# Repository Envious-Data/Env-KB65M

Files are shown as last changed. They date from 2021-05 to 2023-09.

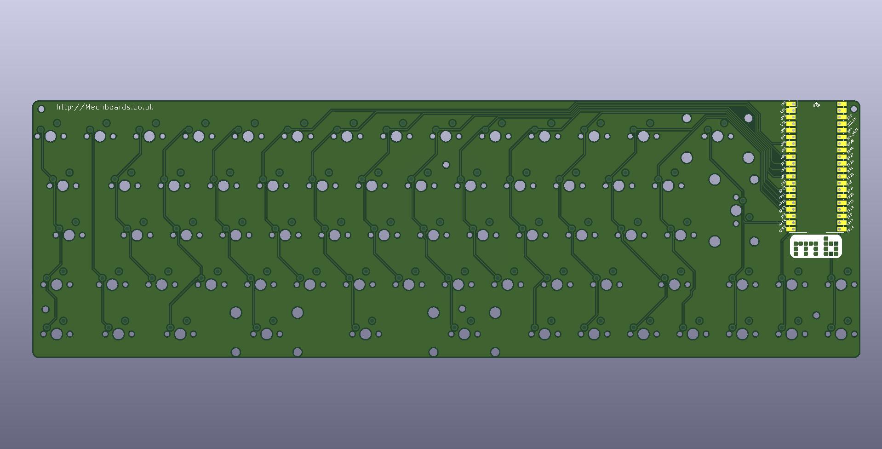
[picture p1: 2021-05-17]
EnvKB65.jpg

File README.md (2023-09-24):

# Env-KB65M
 A 65% Custom Mechanical utilising the raspberry pi pico.
  
### About
A compact 65% design featuring ISO and ANSI layout support as well as a triple split spacebar. I designed this on a whim so its design can be considered somewhat quirky.

### Firmware
If you need a pre-built QMK firmware for this keyboard you can find it [here](https://raw.githubusercontent.com/Envious-Data/EnvKB-QMK/main/_PREBUILTFIRMWARES/enviousdesign_65m_default.uf2)
and [here](https://raw.githubusercontent.com/Envious-Data/EnvKB-QMK/main/_PREBUILTFIRMWARES/enviousdesign_65m_via.uf2)

### how to flash
- hold BOOTSEL button while plugging in USB
- A USB Drive will show up, drag and drop the UF2 file linked above into the Drive
- Done!

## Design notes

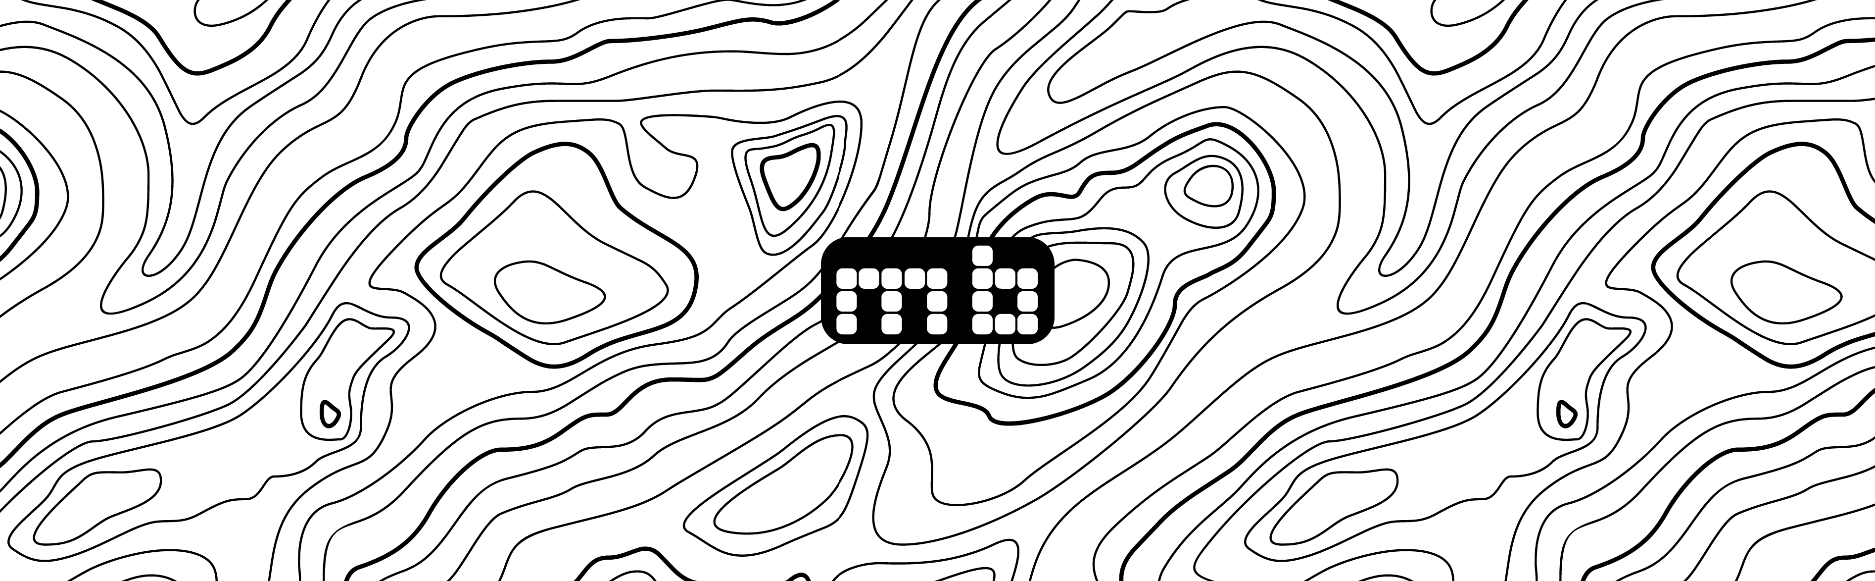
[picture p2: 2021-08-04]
BottomPCB/graphictest.png

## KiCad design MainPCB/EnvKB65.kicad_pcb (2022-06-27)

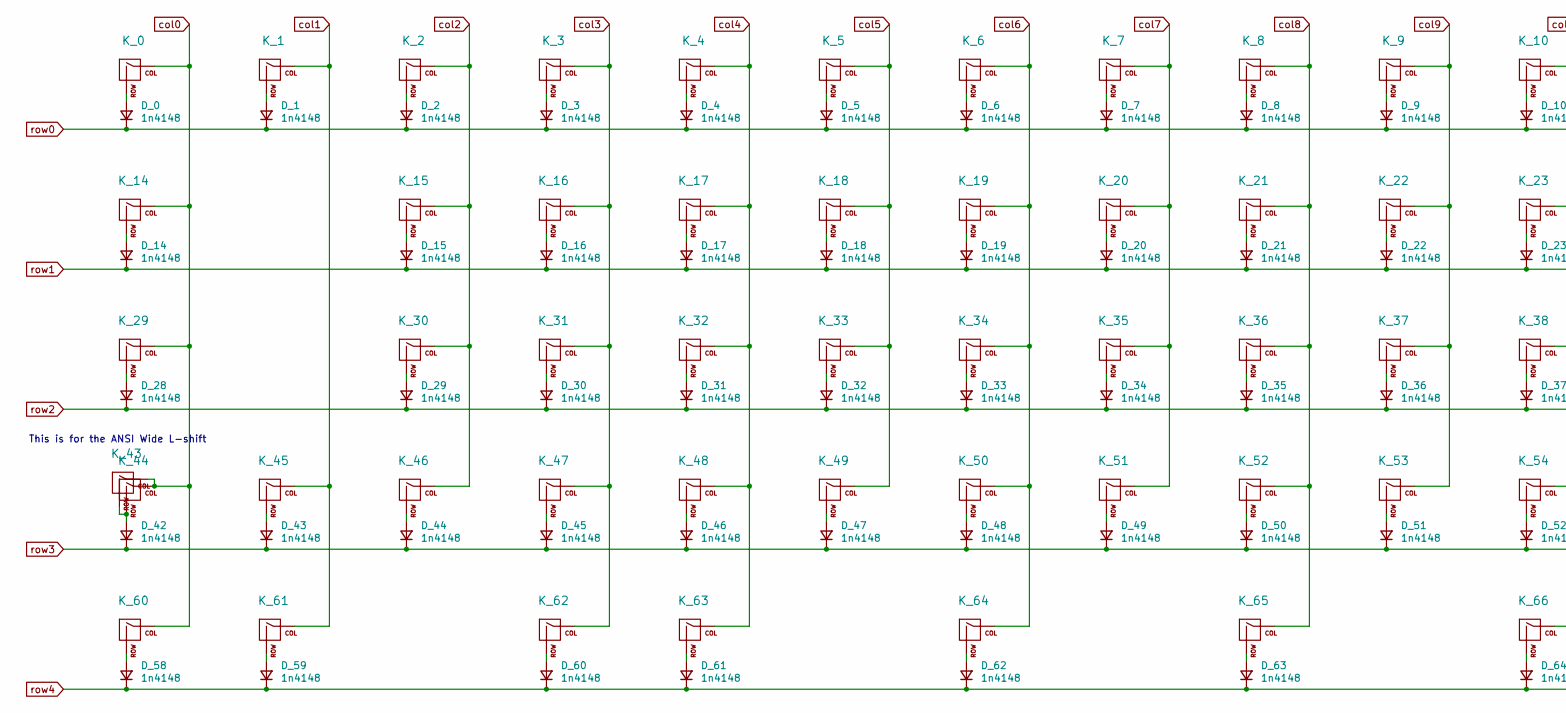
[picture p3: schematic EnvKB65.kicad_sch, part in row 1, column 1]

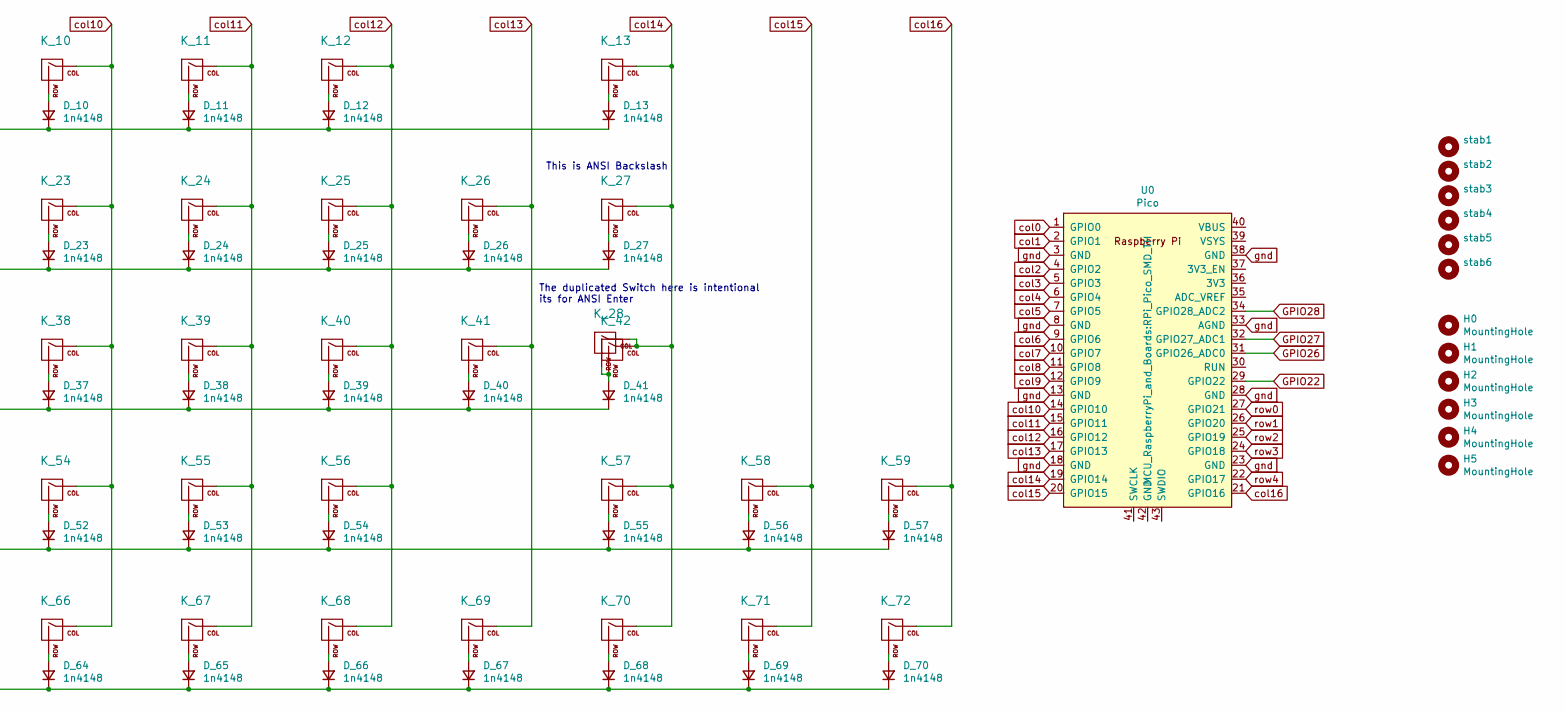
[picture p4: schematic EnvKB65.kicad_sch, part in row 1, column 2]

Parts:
D_0, D_1, D_2, D_3, D_4, D_5, D_6, D_7, D_8, D_9, D_10, D_11, D_12, D_13, D_14, D_15, D_16, D_17, D_18, D_19, D_20, D_21, D_22, D_23, D_24, D_25, D_26, D_27, D_28, D_29, D_30, D_31, D_32, D_33, D_34, D_35, D_36, D_37, D_38, D_39, D_40, D_41, D_42, D_43, D_44, D_45, D_46, D_47, D_48, D_49, D_50, D_51, D_52, D_53, D_54, D_55, D_56, D_57, D_58, D_59, D_60, D_61, D_62, D_63, D_64, D_65, D_66, D_67, D_68, D_69, D_70: 1n4148; D_SOD-123
H0, H1, H2, H3, H4, H5: MountingHole; MountingHole_4.3mm_M4
K_0, K_1, K_2, K_3, K_4, K_5, K_6, K_7, K_8, K_9, K_10, K_11, K_12, K_13, K_14, K_15, K_16, K_17, K_18, K_19, K_20, K_21, K_22, K_23, K_24, K_25, K_26, K_27, K_28, K_29, K_30, K_31, K_32, K_33, K_34, K_35, K_36, K_37, K_38, K_39, K_40, K_41, K_42, K_43, K_44, K_45, K_46, K_47, K_48, K_49, K_50, K_51, K_52, K_53, K_54, K_55, K_56, K_57, K_58, K_59, K_60, K_61, K_62, K_63, K_64, K_65, K_66, K_67, K_68, K_69, K_70, K_71, K_72: MX Switch; MXOnly-1U-NoLED
U0: Pico; RPi_Pico_SMD_TH
stab1, stab2, stab3, stab4, stab5, stab6: Stabilizer; Stabilizer_Cherry_MX_2u

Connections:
GPIO22: U0.29 (GPIO22)
GPIO26: U0.31 (GPIO26_ADC0)
GPIO27: U0.32 (GPIO27_ADC1)
GPIO28: U0.34 (GPIO28_ADC2)
unnamed: D_0.2 (A), K_0.2 (ROW)
unnamed: D_1.2 (A), K_1.2 (ROW)
unnamed: D_2.2 (A), K_2.2 (ROW)
unnamed: D_3.2 (A), K_3.2 (ROW)
unnamed: D_4.2 (A), K_4.2 (ROW)
unnamed: D_5.2 (A), K_5.2 (ROW)
unnamed: D_6.2 (A), K_6.2 (ROW)
unnamed: D_7.2 (A), K_7.2 (ROW)
unnamed: D_8.2 (A), K_8.2 (ROW)
unnamed: D_9.2 (A), K_9.2 (ROW)
unnamed: D_10.2 (A), K_10.2 (ROW)
unnamed: D_11.2 (A), K_11.2 (ROW)
unnamed: D_12.2 (A), K_12.2 (ROW)
unnamed: D_13.2 (A), K_13.2 (ROW)
unnamed: D_14.2 (A), K_14.2 (ROW)
unnamed: D_15.2 (A), K_15.2 (ROW)
unnamed: D_16.2 (A), K_16.2 (ROW)
unnamed: D_17.2 (A), K_17.2 (ROW)
unnamed: D_18.2 (A), K_18.2 (ROW)
unnamed: D_19.2 (A), K_19.2 (ROW)
unnamed: D_20.2 (A), K_20.2 (ROW)
unnamed: D_21.2 (A), K_21.2 (ROW)
unnamed: D_22.2 (A), K_22.2 (ROW)
unnamed: D_23.2 (A), K_23.2 (ROW)
unnamed: D_24.2 (A), K_24.2 (ROW)
unnamed: D_25.2 (A), K_25.2 (ROW)
unnamed: D_26.2 (A), K_26.2 (ROW)
unnamed: D_27.2 (A), K_27.2 (ROW)
unnamed: D_28.2 (A), K_29.2 (ROW)
unnamed: D_29.2 (A), K_30.2 (ROW)
unnamed: D_30.2 (A), K_31.2 (ROW)
unnamed: D_31.2 (A), K_32.2 (ROW)
unnamed: D_32.2 (A), K_33.2 (ROW)
unnamed: D_33.2 (A), K_34.2 (ROW)
unnamed: D_34.2 (A), K_35.2 (ROW)
unnamed: D_35.2 (A), K_36.2 (ROW)
unnamed: D_36.2 (A), K_37.2 (ROW)
unnamed: D_37.2 (A), K_38.2 (ROW)
unnamed: D_38.2 (A), K_39.2 (ROW)
unnamed: D_39.2 (A), K_40.2 (ROW)
unnamed: D_40.2 (A), K_41.2 (ROW)
unnamed: D_41.2 (A), K_28.2 (ROW), K_42.2 (ROW)
unnamed: D_42.2 (A), K_43.2 (ROW), K_44.2 (ROW)
unnamed: D_43.2 (A), K_45.2 (ROW)
unnamed: D_44.2 (A), K_46.2 (ROW)
unnamed: D_45.2 (A), K_47.2 (ROW)
unnamed: D_46.2 (A), K_48.2 (ROW)
unnamed: D_47.2 (A), K_49.2 (ROW)
unnamed: D_48.2 (A), K_50.2 (ROW)
unnamed: D_49.2 (A), K_51.2 (ROW)
unnamed: D_50.2 (A), K_52.2 (ROW)
unnamed: D_51.2 (A), K_53.2 (ROW)
unnamed: D_52.2 (A), K_54.2 (ROW)
unnamed: D_53.2 (A), K_55.2 (ROW)
unnamed: D_54.2 (A), K_56.2 (ROW)
unnamed: D_55.2 (A), K_57.2 (ROW)
unnamed: D_56.2 (A), K_58.2 (ROW)
unnamed: D_57.2 (A), K_59.2 (ROW)
unnamed: D_58.2 (A), K_60.2 (ROW)
unnamed: D_59.2 (A), K_61.2 (ROW)
unnamed: D_60.2 (A), K_62.2 (ROW)
unnamed: D_61.2 (A), K_63.2 (ROW)
unnamed: D_62.2 (A), K_64.2 (ROW)
unnamed: D_63.2 (A), K_65.2 (ROW)
unnamed: D_64.2 (A), K_66.2 (ROW)
unnamed: D_65.2 (A), K_67.2 (ROW)
unnamed: D_66.2 (A), K_68.2 (ROW)
unnamed: D_67.2 (A), K_69.2 (ROW)
unnamed: D_68.2 (A), K_70.2 (ROW)
unnamed: D_69.2 (A), K_71.2 (ROW)
unnamed: D_70.2 (A), K_72.2 (ROW)
col0: K_0.1 (COL), K_14.1 (COL), K_29.1 (COL), K_43.1 (COL), K_44.1 (COL), K_60.1 (COL), U0.1 (GPIO0)
col1: K_1.1 (COL), K_45.1 (COL), K_61.1 (COL), U0.2 (GPIO1)
col2: K_2.1 (COL), K_15.1 (COL), K_30.1 (COL), K_46.1 (COL), U0.4 (GPIO2)
col3: K_3.1 (COL), K_16.1 (COL), K_31.1 (COL), K_47.1 (COL), K_62.1 (COL), U0.5 (GPIO3)
col4: K_4.1 (COL), K_17.1 (COL), K_32.1 (COL), K_48.1 (COL), K_63.1 (COL), U0.6 (GPIO4)
col5: K_5.1 (COL), K_18.1 (COL), K_33.1 (COL), K_49.1 (COL), U0.7 (GPIO5)
col6: K_6.1 (COL), K_19.1 (COL), K_34.1 (COL), K_50.1 (COL), K_64.1 (COL), U0.9 (GPIO6)
col7: K_7.1 (COL), K_20.1 (COL), K_35.1 (COL), K_51.1 (COL), U0.10 (GPIO7)
col8: K_8.1 (COL), K_21.1 (COL), K_36.1 (COL), K_52.1 (COL), K_65.1 (COL), U0.11 (GPIO8)
col9: K_9.1 (COL), K_22.1 (COL), K_37.1 (COL), K_53.1 (COL), U0.12 (GPIO9)
col10: K_10.1 (COL), K_23.1 (COL), K_38.1 (COL), K_54.1 (COL), K_66.1 (COL), U0.14 (GPIO10)
col11: K_11.1 (COL), K_24.1 (COL), K_39.1 (COL), K_55.1 (COL), K_67.1 (COL), U0.15 (GPIO11)
col12: K_12.1 (COL), K_25.1 (COL), K_40.1 (COL), K_56.1 (COL), K_68.1 (COL), U0.16 (GPIO12)
col13: K_26.1 (COL), K_41.1 (COL), K_69.1 (COL), U0.17 (GPIO13)
col14: K_13.1 (COL), K_27.1 (COL), K_28.1 (COL), K_42.1 (COL), K_57.1 (COL), K_70.1 (COL), U0.19 (GPIO14)
col15: K_58.1 (COL), K_71.1 (COL), U0.20 (GPIO15)
col16: K_59.1 (COL), K_72.1 (COL), U0.21 (GPIO16)
gnd: U0.3 (GND), U0.8 (GND), U0.13 (GND), U0.18 (GND), U0.23 (GND), U0.28 (GND), U0.33 (AGND), U0.38 (GND)
row0: D_0.1 (K), D_1.1 (K), D_2.1 (K), D_3.1 (K), D_4.1 (K), D_5.1 (K), D_6.1 (K), D_7.1 (K), D_8.1 (K), D_9.1 (K), D_10.1 (K), D_11.1 (K), D_12.1 (K), D_13.1 (K), U0.27 (GPIO21)
row1: D_14.1 (K), D_15.1 (K), D_16.1 (K), D_17.1 (K), D_18.1 (K), D_19.1 (K), D_20.1 (K), D_21.1 (K), D_22.1 (K), D_23.1 (K), D_24.1 (K), D_25.1 (K), D_26.1 (K), D_27.1 (K), U0.26 (GPIO20)
row2: D_28.1 (K), D_29.1 (K), D_30.1 (K), D_31.1 (K), D_32.1 (K), D_33.1 (K), D_34.1 (K), D_35.1 (K), D_36.1 (K), D_37.1 (K), D_38.1 (K), D_39.1 (K), D_40.1 (K), D_41.1 (K), U0.25 (GPIO19)
row3: D_42.1 (K), D_43.1 (K), D_44.1 (K), D_45.1 (K), D_46.1 (K), D_47.1 (K), D_48.1 (K), D_49.1 (K), D_50.1 (K), D_51.1 (K), D_52.1 (K), D_53.1 (K), D_54.1 (K), D_55.1 (K), D_56.1 (K), D_57.1 (K), U0.24 (GPIO18)
row4: D_58.1 (K), D_59.1 (K), D_60.1 (K), D_61.1 (K), D_62.1 (K), D_63.1 (K), D_64.1 (K), D_65.1 (K), D_66.1 (K), D_67.1 (K), D_68.1 (K), D_69.1 (K), D_70.1 (K), U0.22 (GPIO17)

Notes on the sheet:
The duplicated Switch here is intentional its for ANSI Enter
This is ANSI Backslash
This is for the ANSI Wide L-shift

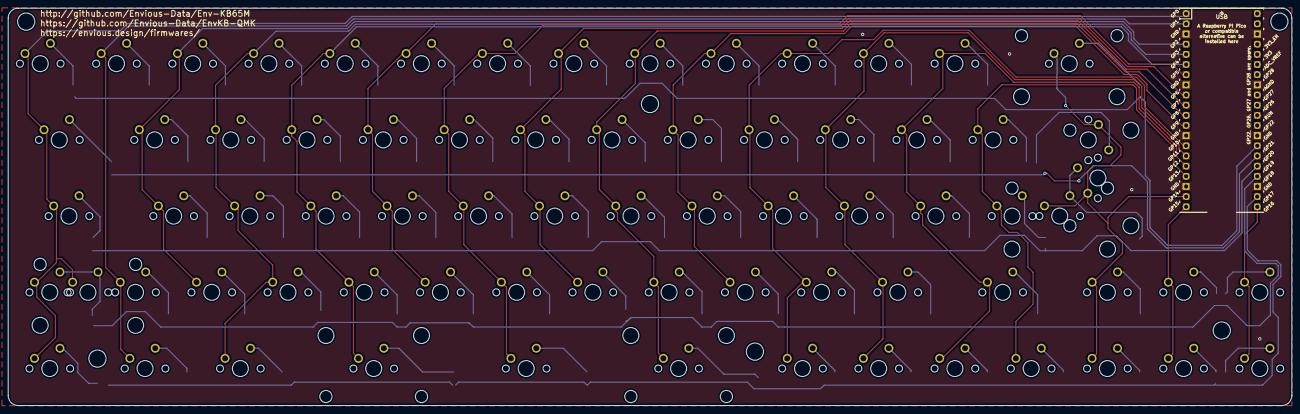
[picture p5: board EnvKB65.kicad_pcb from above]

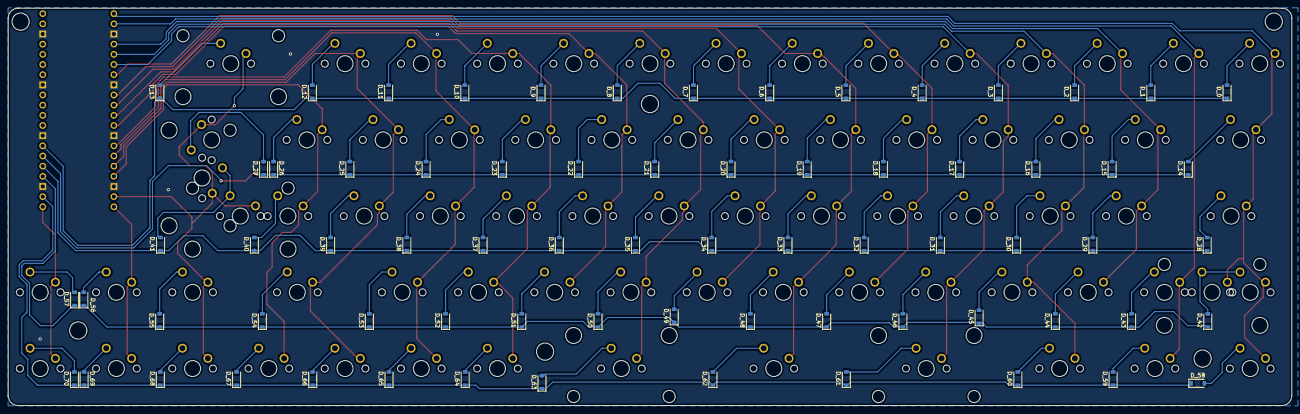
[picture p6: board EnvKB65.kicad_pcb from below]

Board: 2 copper layers, 320.8 x 99.3 mm, 157 parts (71 on the bottom side), 94 nets.

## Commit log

2021-05-16 Initial commit+1
    [EnvKB65.kicad_pcb, EnvKB65.sch]
2021-05-17 slimmed design down a bit at the cost of some keys
    [EnvKB65.kicad_pcb, EnvKB65.sch]
2021-05-17 Routed Traces, Add Mounting holes and edge cuts
    [EnvKB65.kicad_pcb, EnvKB65.sch]
2021-05-17 Final Adjustments And Gerber Creation for Revision0
    [EnvKB65-B_Cu.gbr, EnvKB65-B_Mask.gbr, EnvKB65-B_Paste.gbr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]
2021-05-17 Changed Diodes to SOD-323 and separated Position files
    [EnvKB65-B_Cu.gbr, EnvKB65-B_Mask.gbr, EnvKB65-B_Paste.gbr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]
2021-05-17 corrected issue + made blank bottom PCB
    [EnvKB65-B_Cu.gbr, EnvKB65-B_Mask.gbr, EnvKB65-B_Paste.gbr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]
2021-05-17 General Cleanup, board resize and correction of things + made top switch plate
    [EnvKB65-B_Cu.gbr, EnvKB65-B_Mask.gbr, EnvKB65-B_Paste.gbr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]
2021-05-27 Swapped out mechboads logo for personal order
    [EnvKB65-B_Cu.gbr, EnvKB65-B_Mask.gbr, EnvKB65-B_Paste.gbr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]
2021-05-27 General cleanup and testing of improved Gerber generation
    [EnvKB65-B_Cu.gbr, EnvKB65-B_Mask.gbr, EnvKB65-B_Paste.gbr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]
2021-05-31 Added ANSI support, generated Gerbers and sent to JLCPCB
    [EnvKB65-B_Cu.gbl, EnvKB65-B_Mask.gbs, EnvKB65-B_Paste.gbp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]
2021-05-31 Embiggened the PCB to allow for 4mm edge spaces to comply with JLCPCB
    [EnvKB65-SwitchPlate-B_Cu.gbl, EnvKB65-SwitchPlate-B_Mask.gbs, EnvKB65-SwitchPlate-B_Paste.gbp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]
2021-06-11 corrected a couple silkscreen issues and moved some traces further from some holes.
    [EnvKB65.kicad_pcb]
2021-06-22 Mount hole tweak to allow for switches to seat properly with a spacer installed
    [EnvKB65-SwitchPlate.kicad_pcb, EnvKB65-SwitchPlate.sch, EnvKB65.kicad_pcb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]
2021-06-28 moved some mount holes a tiny bit and adjusted some traces for wider clearance.
    [EnvKB65-SwitchPlate.kicad_pcb, EnvKB65.kicad_pcb, EnvKB65_bottom.kicad_pcb]
2021-07-10 moved mount hole#6 up by 1mm and changed stabilizer cut out.
    [EnvKB65-SwitchPlate.kicad_pcb, EnvKB65.kicad_pcb, EnvKB65_bottom.kicad_pcb]
2021-07-29 Cleaned up a couple strange mistakes.
    [EnvKB65.kicad_pcb]
2021-07-29 removed redundant url.
    [EnvKB65_bottom.kicad_pcb]
2021-07-29 moved mount hole "H5" to the right by 40.5mm on all PCBs
    [EnvKB65-SwitchPlate.kicad_pcb, EnvKB65.kicad_pcb, EnvKB65_bottom.kicad_pcb]
2021-07-30 replaced all mount holes with versions that have pads
    I did this because the pcb can get scraped up if you take it apart a bunch of times to clean it, hopefully this mitigates that.
    [EnvKB65-SwitchPlate.kicad_pcb, EnvKB65-SwitchPlate.sch, EnvKB65.kicad_pcb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]
2021-08-04 Generated some Gerbers and added some testing graphics for now.
    [EnvKB65-B_Cu.gbl, EnvKB65-B_Mask.gbs, EnvKB65-B_Paste.gbp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]
2021-08-14 started work on a version with an onboard atmega32u4
    [EnvKB65-32u4.kicad_pcb, EnvKB65-32u4.sch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]
2021-08-15 changed my mind, I wanted the 32u version to have more switches, going to figure out if I can fit the MCU somewhere on the back of the board.
    [EnvKB65-32u4.kicad_pcb, EnvKB65-32u4.sch, EnvKB65.kicad_pcb]
2021-08-15 finished running traces, probably need to clean up some bits and pieces.
    [EnvKB65-32u4.kicad_pcb, EnvKB65-32u4.sch]
2021-08-15 adjusted some bits to comply with DRC.
    [EnvKB65-32u4.kicad_pcb]
2021-08-16 a decoupling capacitor was in a bad position
    [EnvKB65-32u4.kicad_pcb]
2021-08-22 updated silkscreen and also made 32u switch plate.
    [65-32u4-TopPCB.kicad_pcb, 65-32u4-TopPCB.sch, EnvKB65-32u4.kicad_pcb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]
2021-08-22 generated updated gerbers for 32u4 version
    [EnvKB65-SwitchPlate-B_Cu.gbl, EnvKB65-SwitchPlate-B_Mask.gbs, EnvKB65-SwitchPlate-B_Paste.gbp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]
2021-08-22 started work on a RP2040 version with the same layout as the 32u4 version
    [EnvKB65-2040.kicad_pcb, EnvKB65-2040.sch]
2021-08-22 continued work on the RP2040 version
    [EnvKB65-2040.kicad_pcb, EnvKB65-2040.sch]
2021-08-22 finished off RP2040 version, needs general check overs and cleanup.
    [EnvKB65-2040.kicad_pcb, EnvKB65-2040.sch]
2021-08-22 moved some resistors and capacitors to account for screw hole clearance for the stabilizer holes.
    [EnvKB65-2040.kicad_pcb]
2021-10-05 See List
    * removed RP2040 and atmega32u4 versions
    * updated main PCB to have larger holes
    * fixed some stuff on the main PCB and added some labels
    [65-32u4-TopPCB.kicad_pcb, 65-32u4-TopPCB.sch, EnvKB65-2040.kicad_pcb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]
2021-10-05 Generated Up to date gerbers.
    [EnvKB65-SwitchPlate-B_Cu.gbl, EnvKB65-SwitchPlate-B_Mask.gbs, EnvKB65-SwitchPlate-B_Paste.gbp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]
2021-10-30 Started work on hotswap version
    [EnvKB65.kicad_pcb, EnvKB65.sch]
2021-10-30 small cleanup + worked on routing races and all
    [EnvKB65.kicad_pcb]
2021-10-31 fixed some trace and pad/hole conflictions and spaced some traces although not causing DRC errors.
    [EnvKB65.kicad_pcb]
2021-10-31 Renamed KiCad Project appropriately
    [EnvKB65HS.kicad_pcb, EnvKB65HS.sch]
2021-10-31 Generated Gerber, fixed gitignore
    [EnvKB65HS.kicad_pcb, EnvKB65HS_bom_jlc.csv, EnvKB65_bom_jlc.csv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]
2021-10-31 corrected hotswap socket being cut off on the left side (PCB is slightly wider)
    [EnvKB65HS.kicad_pcb]
2021-12-04 adjusted design and fixed issues, Generated updated gerber
    [EnvKB65HS.kicad_pcb, EnvKB65HS.sch]
2021-12-04 moved gerber to correct place
2021-12-04 updated BOM and CPL
    [EnvKB65HS_bom_jlc.csv]
2021-12-04 added switch plate to ECO2
    [EnvKB65HS-Eco2_User.dxf, EnvKB65HS.kicad_pcb]
2021-12-05 Generated updated Gerber
    [EnvKB65HS-Eco2_User.dxf, EnvKB65HS.kicad_pcb]
2022-01-16 made some fixes to silkscreen and a general check over to prepare for ordering.
2022-04-15 some small fixes
    [EnvKB65-SwitchPlate.kicad_pcb]
2022-05-06 smol checkthrough and gerber generation of 65 hotswap
    [EnvKB65HS.kicad_sch]
2022-05-10 various corrections and updated gerbers, bom, cpls
    [EnvKB65.kicad_pcb, EnvKB65.kicad_sch, EnvKB65.sch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]
2022-05-17 updated gerbers, BOM and CPL
    [EnvKB65HS_bom_jlc.csv, EnvKB65_bom_jlc.csv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]
2022-05-28 updated switch plate to be PCB mount only.
    [EnvKB65-SwitchPlate.kicad_pcb]
2022-05-28 Removed Mechboards branding as there is now a mechboards fork
    [EnvKB65-SwitchPlate.kicad_pcb, EnvKB65_bottom.kicad_pcb]
2022-05-28 added i2c header for oled
    [EnvKB65HS.kicad_sch]
2022-05-30 some tweaks to traces here and there to ensure decent clearance
2022-06-01 updated gerber
2022-06-02 some small correction to a couple traces
2022-06-12 swapped mount holes to solderable inserts and fixed some potential clearance issues
    [EnvKB65HS.kicad_sch]
2022-06-12 larger holes for aliexpress smd mounts
    [EnvKB65HS.kicad_pcb]
2022-06-18 swapped mount holes back and generated updated gerbers and etc
    [EnvKB65HS.kicad_pcb, EnvKB65HS.kicad_sch]
2022-06-27 swapped diodes to larger footprint and corrected DRC errors
    [EnvKB65.kicad_pcb, EnvKB65.kicad_sch, EnvKB65HS.kicad_pcb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]
2022-07-04 added GND plane fill, generated updated gerber
2022-11-05 created choc V2 variant with plate on user layer
    [EnvKB65.kicad_sch]
2023-02-10 added HOTSWAP version to gerber folder
    [EnvKB65HS_bom_jlc.csv, EnvKB65_bom_jlc.csv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]
2023-09-24 small repo cleanup + updated readme
    [EnvKB65HS_bom_jlc.csv, EnvKB65_bom_jlc.csv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]
